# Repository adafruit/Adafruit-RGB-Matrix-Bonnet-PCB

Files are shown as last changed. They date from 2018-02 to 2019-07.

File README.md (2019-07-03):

## Adafruit RGB LED Matrix Display Bonnet PCB

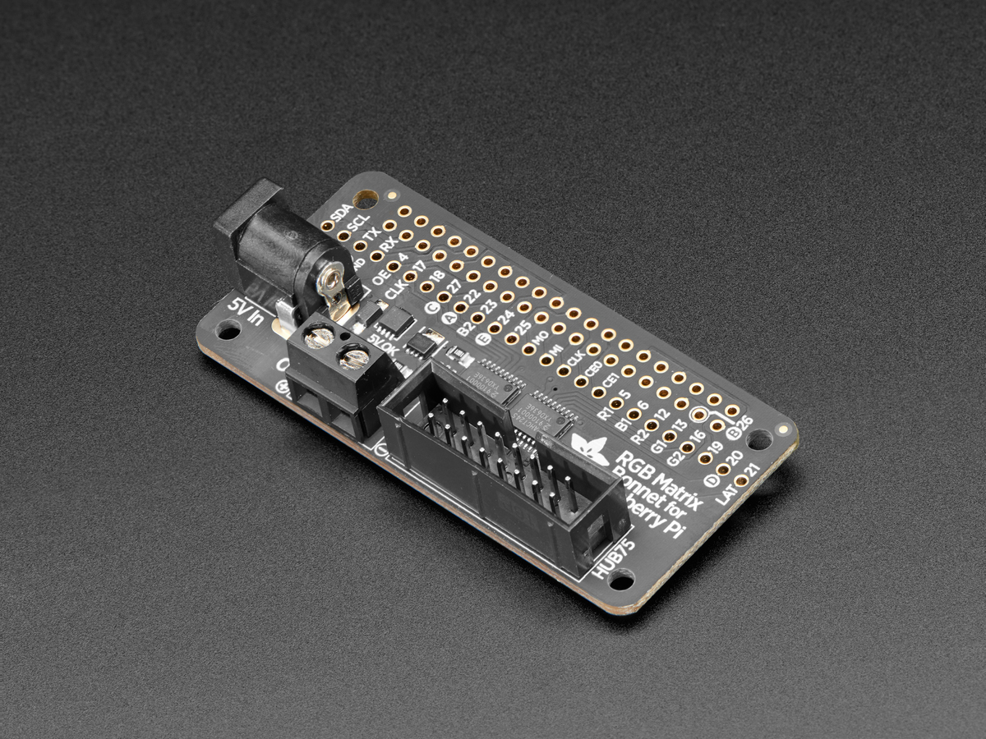
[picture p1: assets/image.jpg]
<a href="http://www.adafruit.com/products/3211"><br/>
Click here to purchase one from the Adafruit shop</a>

PCB files for the Adafruit RGB Matrix Bonnet. Format is EagleCAD schematic and board layout

For more details, check out the product page at
* https://www.adafruit.com/product/3211

### Description

You can now create a dazzling display with your Raspberry Pi with the Adafruit RGB Matrix Bonnet. These boards plug into your Pi and makes it super easy to control RGB matrices such as those we stock in the shop and create a colorful scrolling display or mini LED wall with ease.

"Bonnet" boards work on any Raspberry Pi with a 40-pin GPIO header — Zero, Zero W/WH, Model A+, B+, Pi 2 and Pi 3. They do not work with older 26-pin boards like the original Model A or B. Note with the Pi Zero you may need to solder a header on the Pi board; it’s normally unpopulated on that model.

We also have an older, HAT version of our RGB Matrix design. The HAT version does not come fully assembled, does not support 1/32-scan matrices, but does come with a real time clock (RTC)

This bonnet will make your matrix projects super easy and avoids wiring complexity.

Please note: this Bonnet is only for use with HUB75 type RGB matrices. Not for use with NeoPixel, DotStar, or other 'addressable' LEDs.

### License

Adafruit invests time and resources providing this open source design, please support Adafruit and open-source hardware by purchasing products from [Adafruit](https://www.adafruit.com)!

Designed for Adafruit Industries.

Creative Commons Attribution/Share-Alike, all text above must be included in any redistribution. See license.txt for additional details.

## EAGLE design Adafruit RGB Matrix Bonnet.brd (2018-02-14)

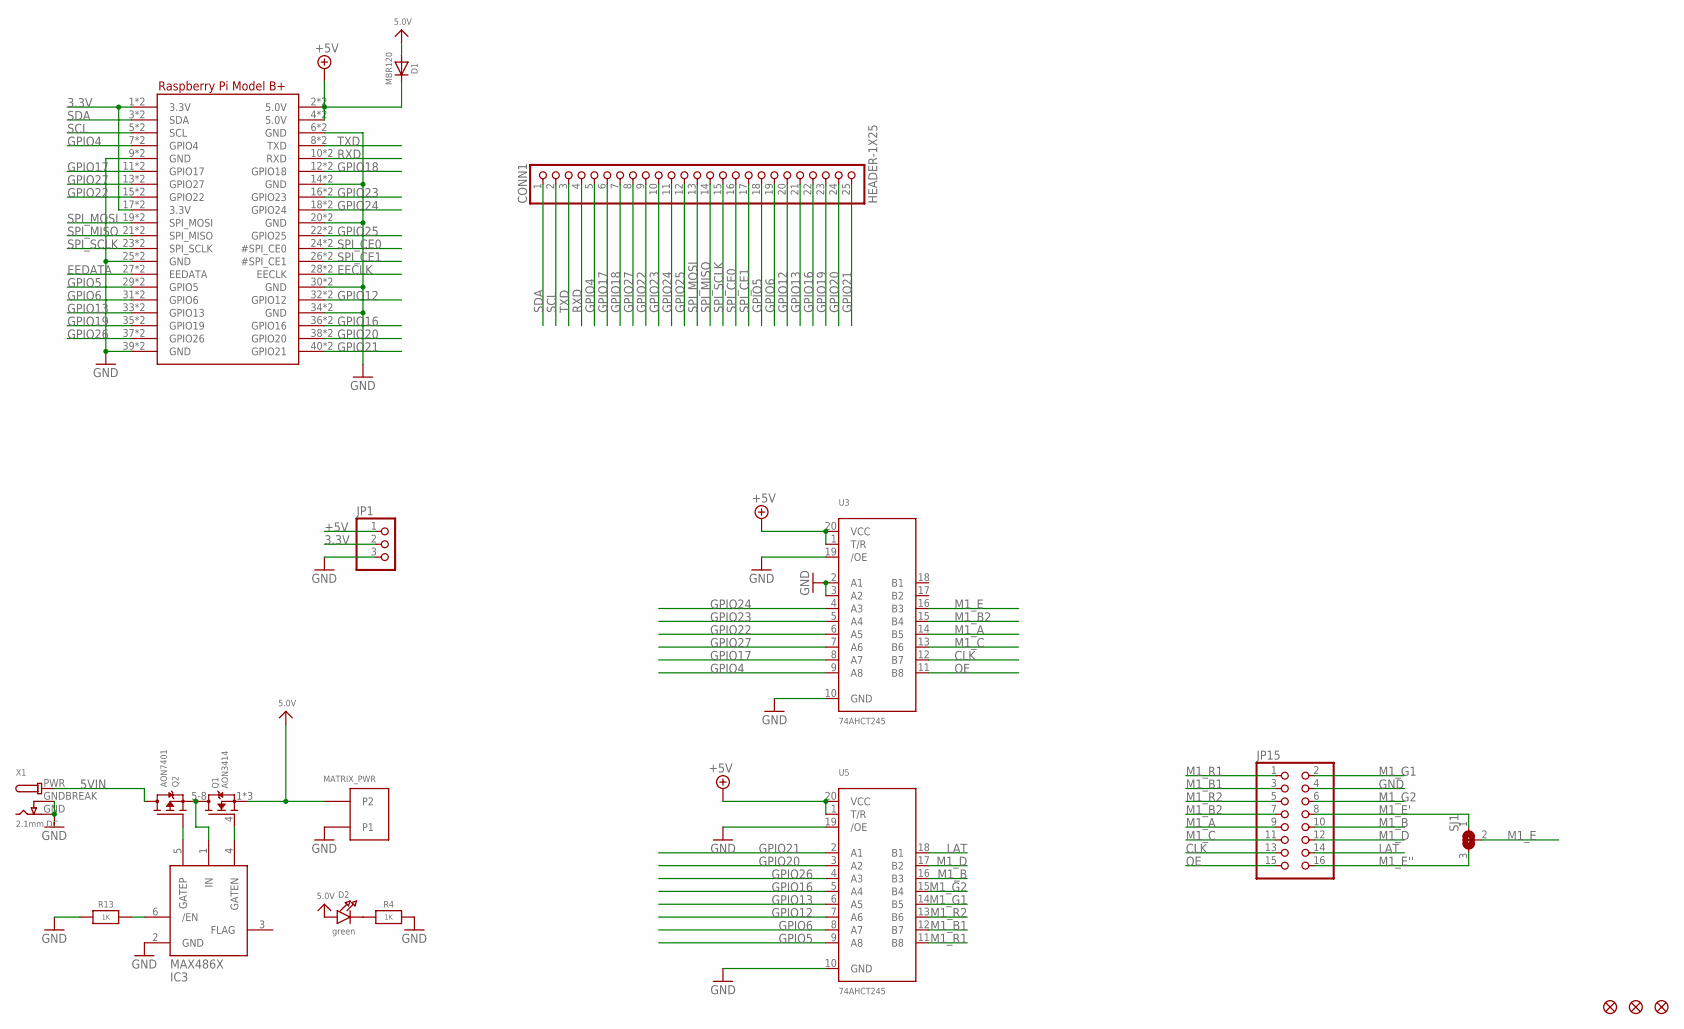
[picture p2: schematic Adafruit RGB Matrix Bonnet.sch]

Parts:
CONN1: HEADER-1X25; 1X25_ROUND_70MIL
D1: MBR120; SOD-123
D2: green; CHIPLED_0805_NOOUTLINE
FID1, FID2, FID3: FIDUCIAL_1MM
IC3: MAX4866T; SOT23-6
JP1: HEADER-1X376MIL; 1X03_ROUND_76
JP15: HEADER-2X8_SHROUDED; 2X08_SHROUDED
MATRIX_PWR: PINHEAD; TERMBLOCK508
Q1: AON3414; POWERPAK-1212-8
Q2: AON7401; POWERDI3333
R4, R13: 1K; 0805-NO
RPI1: RASPBERRYPI_BPLUS_BONNET_THMSMT; PI_BONNET_THMSMT
SJ1: SOLDERJUMPER_2WAY; SOLDERJUMPER_2WAY_OPEN_NOPASTE
U3, U5: 74AHCT245; TSSOP20
X1: 2.1mm DC; DCJACK_2MM_PTH

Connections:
3.3V: JP1.2, RPI1.1 (3.3V), RPI1.17 (3.3V), RPI1.S1 (3.3V), RPI1.S17 (3.3V)
5.0V: D1.A, D2.A, MATRIX_PWR.P$4 (P2), Q1.1 (S), Q1.2 (S), Q1.3 (S)
5VIN: Q2.5678 (D), X1.PWR
+5V: D1.C, JP1.1, RPI1.2 (5.0V), RPI1.4 (5.0V), RPI1.S2 (5.0V), RPI1.S4 (5.0V), U3.1 (T/R), U3.20 (VCC), U5.1 (T/R), U5.20 (VCC)
CLK: JP15.13, U3.12 (B7)
EECLK: RPI1.28 (EECLK), RPI1.S28 (EECLK)
EEDATA: RPI1.27 (EEDATA), RPI1.S27 (EEDATA)
GND: IC3.2 (GND), JP1.3, JP15.4, MATRIX_PWR.P$3 (P1), R4.2, R13.1, RPI1.6 (GND), RPI1.9 (GND), RPI1.14 (GND), RPI1.20 (GND), RPI1.25 (GND), RPI1.30 (GND), RPI1.34 (GND), RPI1.39 (GND), RPI1.S6 (GND), RPI1.S9 (GND), RPI1.S14 (GND), RPI1.S20 (GND), RPI1.S25 (GND), RPI1.S30 (GND), RPI1.S34 (GND), RPI1.S39 (GND), U3.2 (A1), U3.3 (A2), U3.10 (GND), U3.19 (/OE), U5.10 (GND), U5.19 (/OE), X1.GND, X1.GNDBREAK
GPIO4: CONN1.5, RPI1.7 (GPIO4), RPI1.S7 (GPIO4), U3.9 (A8)
GPIO5: CONN1.18, RPI1.29 (GPIO5), RPI1.S29 (GPIO5), U5.9 (A8)
GPIO6: CONN1.19, RPI1.31 (GPIO6), RPI1.S31 (GPIO6), U5.8 (A7)
GPIO12: CONN1.20, RPI1.32 (GPIO12), RPI1.S32 (GPIO12), U5.7 (A6)
GPIO13: CONN1.21, RPI1.33 (GPIO13), RPI1.S33 (GPIO13), U5.6 (A5)
GPIO16: CONN1.22, RPI1.36 (GPIO16), RPI1.S36 (GPIO16), U5.5 (A4)
GPIO17: CONN1.6, RPI1.11 (GPIO17), RPI1.S11 (GPIO17), U3.8 (A7)
GPIO18: CONN1.7, RPI1.12 (GPIO18), RPI1.S12 (GPIO18)
GPIO19: CONN1.23, RPI1.35 (GPIO19), RPI1.S35 (GPIO19)
GPIO20: CONN1.24, RPI1.38 (GPIO20), RPI1.S38 (GPIO20), U5.3 (A2)
GPIO21: CONN1.25, RPI1.40 (GPIO21), RPI1.S40 (GPIO21), U5.2 (A1)
GPIO22: CONN1.9, RPI1.15 (GPIO22), RPI1.S15 (GPIO22), U3.6 (A5)
GPIO23: CONN1.10, RPI1.16 (GPIO23), RPI1.S16 (GPIO23), U3.5 (A4)
GPIO24: CONN1.11, RPI1.18 (GPIO24), RPI1.S18 (GPIO24), U3.4 (A3)
GPIO25: CONN1.12, RPI1.22 (GPIO25), RPI1.S22 (GPIO25)
GPIO26: RPI1.37 (GPIO26), RPI1.S37 (GPIO26), U5.4 (A3)
GPIO27: CONN1.8, RPI1.13 (GPIO27), RPI1.S13 (GPIO27), U3.7 (A6)
LAT: JP15.14, U5.18 (B1)
M1_A: JP15.9, U3.14 (B5)
M1_B: JP15.10, U5.16 (B3)
M1_B1: JP15.3, U5.12 (B7)
M1_B2: JP15.7, U3.15 (B4)
M1_C: JP15.11, U3.13 (B6)
M1_D: JP15.12, U5.17 (B2)
M1_E: SJ1.2, U3.16 (B3)
M1_E': JP15.8, SJ1.1
M1_E'': JP15.16, SJ1.3
M1_G1: JP15.2, U5.14 (B5)
M1_G2: JP15.6, U5.15 (B4)
M1_R1: JP15.1, U5.11 (B8)
M1_R2: JP15.5, U5.13 (B6)
unnamed: IC3.6 (/EN), R13.2
unnamed: D2.C, R4.1
unnamed: IC3.1 (IN), Q1.5-8 (D), Q2.1 (S), Q2.2 (S), Q2.3 (S)
unnamed: IC3.4 (GATEN), Q1.4 (G)
unnamed: IC3.5 (GATEP), Q2.4 (G)
OE: JP15.15, U3.11 (B8)
RXD: CONN1.4, RPI1.10 (RXD), RPI1.S10 (RXD)
SCL: CONN1.2, RPI1.5 (SCL), RPI1.S5 (SCL)
SDA: CONN1.1, RPI1.3 (SDA), RPI1.S3 (SDA)
SPI_CE0: CONN1.16, RPI1.24 (#SPI_CE0), RPI1.S24 (#SPI_CE0)
SPI_CE1: CONN1.17, RPI1.26 (#SPI_CE1), RPI1.S26 (#SPI_CE1)
SPI_MISO: CONN1.14, RPI1.21 (SPI_MISO), RPI1.S21 (SPI_MISO)
SPI_MOSI: CONN1.13, RPI1.19 (SPI_MOSI), RPI1.S19 (SPI_MOSI)
SPI_SCLK: CONN1.15, RPI1.23 (SPI_SCLK), RPI1.S23 (SPI_SCLK)
TXD: CONN1.3, RPI1.8 (TXD), RPI1.S8 (TXD)

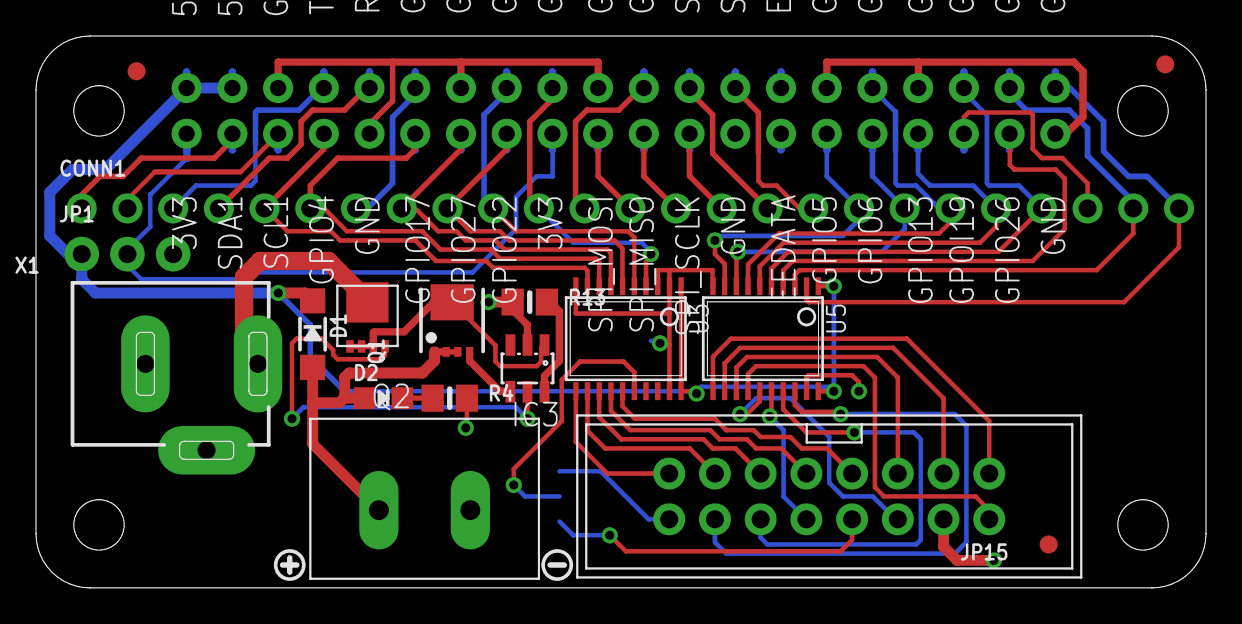
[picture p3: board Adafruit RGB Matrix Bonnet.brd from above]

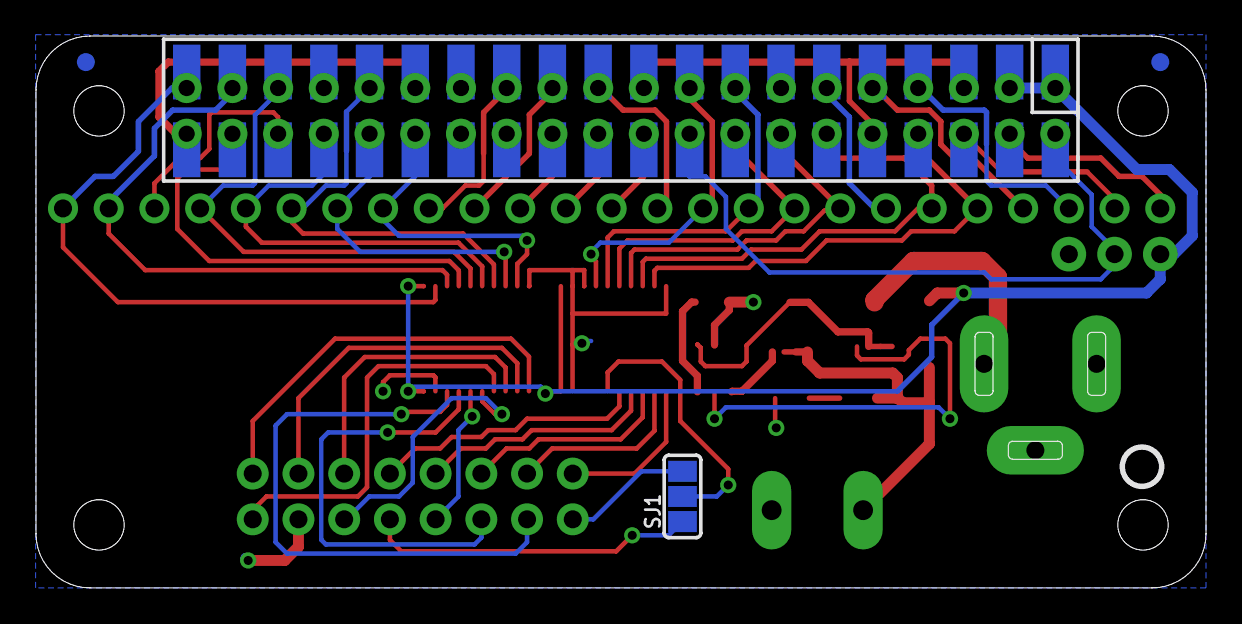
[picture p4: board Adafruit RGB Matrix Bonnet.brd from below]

Board: 2 copper layers, 65.0 x 30.7 mm, 24 parts (3 on the bottom side), 54 nets.

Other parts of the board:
U$1: BONNET_MATRIX_TOP
U$3: PCBFEAT-REV-056
U$6: BONNET_MATRIX_BOT
U$10: SYMBOL_PLUS
U$11: SYMBOL_MINUS

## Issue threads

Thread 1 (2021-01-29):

Adafruit bonnet issue with raspberrypi-4 POE connector

reinierdevl, 2021-01-29:
The POE connector of the pi-4 touches the bonnet causuing short-circuits and does not allow the bonnet to be seated well

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

ladyada, 2021-01-29:
yeah its very annoying - this bonnet came out before the poe. use a lifter!
https://www.adafruit.com/product/4079

reinierdevl, 2021-01-30:
where in the netherlands can I buy this, I find no-one selling them and getting them from your site will bring an insane17euro shipping costs

Closed 2021-01-29.

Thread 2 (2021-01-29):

output voltage drop when max brightness

reinierdevl, 2021-01-29:
It states in the manual that the power protection circuit is also there to protect the pi and can be used to power the pi

    this means that if you accidentally grab a 9V or 12V plug or a reverse
    polarity plug you will not damage the bonnet, Pi and panels

and

    So if you want, just plug in the 5V wall adapter into the
    bonnet and it will automagically power up the Pi too!

This will work with less than max brightness and 1 32x32 panel although there is a voltage drop upto 4.8 or so, but with two panels I see the output voltage of the bonnet drop to 4.56V which is too little to power a pi. The panels are more tolerant for low voltage but the pi isn't. I had several crashes when I wanted to lit the 2 32x32 panel at maximum white brightness for my application, which caused the pi to crash, before I found out

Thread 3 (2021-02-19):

Minor hardware suggestions

marekm72, 2021-02-19:
I'd like to suggest minor hardware design changes to allow separate +5V power supply for the LED matrix without power sequencing requirements.  Planning to drive the matrix (32x32, 1:8 scan) from the CM4IO board which has onboard +12V to +5V buck converter for the CM4 - but it has not enough power for the matrix, which will be powered separately.  So the LED matrix should be powered up before the RPi, otherwise the logic high outputs of the bonnet are clamped by the plain old 74HC logic to the matrix Vcc.

Unlike plain old 74HC, the 74AHCT logic chips in the hat/bonnet accept 3.3V input levels ('T' stands for TTL) and also input voltages higher than power supply ('A' - no clamping of high inputs to Vcc even at 0V).  But the '245 is bi-directional (here unnecessarily) and high-Z I/O pins don't have this capability (only purely input pins do), so I'd suggest to use the uni-directional 74AHCT541 instead, and power it from the same +5V power supply as the LED matrix (separate from the RPi +5V).  This way both power supplies can go up/down in any order.

While you're at it, I'd suggest adding a another (solder) jumper on the D row select pin as well - 1:8 scan matrix only has A, B, C and the one I have has D grounded.  So it is better to disconnect that pin to avoid a short-circuit if driven high by the GPIO.

About the higher quality option (use PWM for matrix BLANK, no sound) - do both GPIO4 and GPIO18 need to be shorted, or is it OK to just use GPIO18 only (PWM) and free up GPIO4 for other use?

ladyada, 2021-02-21:
thanx!

Closed 2021-02-21.

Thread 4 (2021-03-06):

power loss over Bonnet

reinierdevl, 2021-03-06:
Although the documentation mentions that you can power the pi from the bonnet,

> So if you want, just plug in the 5V wall adapter into the
bonnet and it will automagically power up the Pi too!

the voltage drop over the FETS is too high, certainly when you use more/larger panels at full brightness. I checked the bonnet output for a 64x32 panel (2x 32x32) and I see there is a huge voltage drop over the bonnet...at the 3.5A required the output voltage drops to 4.6V, which is too low for the Pi and it crashes.

I do not recommend powering the Pi from the bonnet

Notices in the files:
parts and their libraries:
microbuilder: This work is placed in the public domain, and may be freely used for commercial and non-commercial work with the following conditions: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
